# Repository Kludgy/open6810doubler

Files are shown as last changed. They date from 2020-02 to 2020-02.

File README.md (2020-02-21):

Open 6810 Doubler for the Atari 1050 Disk Drive
===============================================

This repository holds KiCad files for a PCB that, when used in conjunction with a custom Atari 1050 ROM, increases the available SRAM in a stock Atari 1050 Disk Drive from 128 bytes to 256 bytes. The 256 bytes of RAM is presumably enough to fit an entire sector's worth of data. Far more information can be found here: http://blog.3b2.sk/igi/post/Atari-1050-ICD-US-doubler.aspx

BOM: 
* 2x MCM6810.
* 2x Pin Header Strips to socket the PCB into the original 6810 location on the mainboard.
* 1x 24-pin socket on the mainboard as you wish.

Be advised the PCB will need to be socketed high enough to clear other components on the board.

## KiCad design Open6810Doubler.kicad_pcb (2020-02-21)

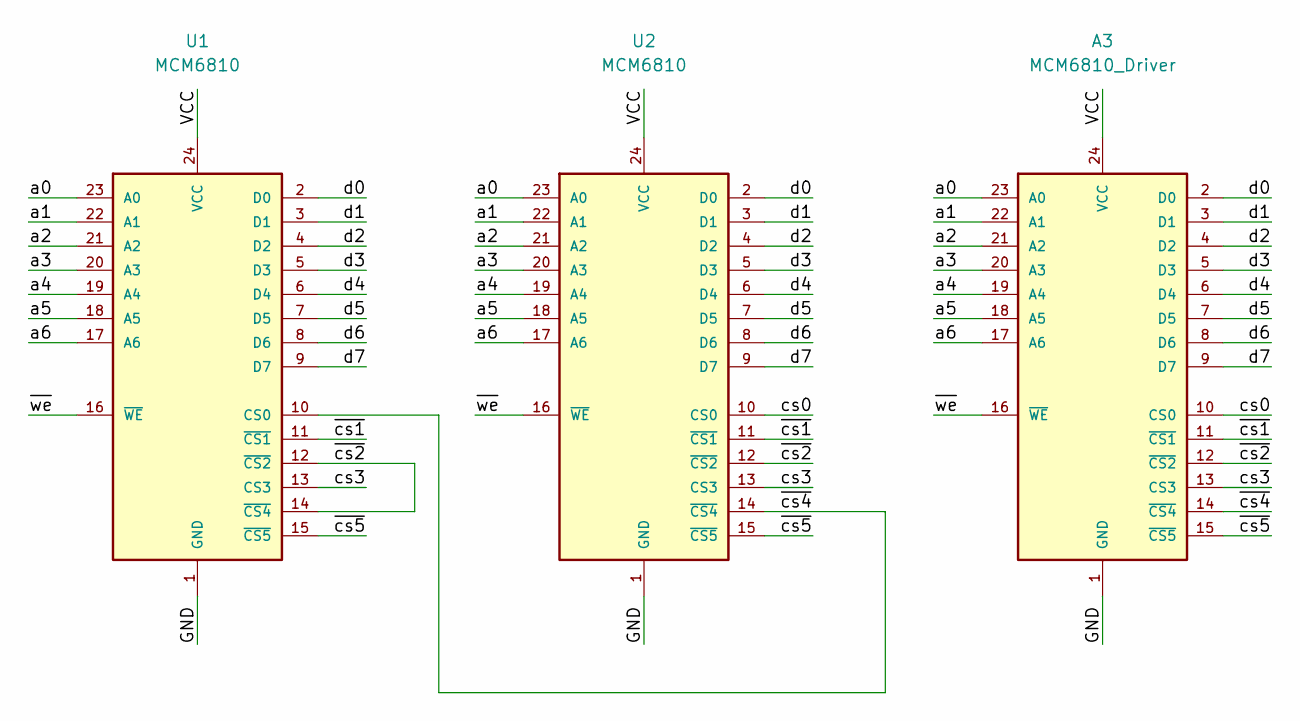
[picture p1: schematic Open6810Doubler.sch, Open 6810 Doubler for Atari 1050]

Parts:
A3: MCM6810_Driver; DIP-24_W15.24mm_LongPads
U1, U2: MCM6810; DIP-24_W15.24mm_LongPads

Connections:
/GND: A3.1 (GND), U1.1 (GND), U2.1 (GND)
/VCC: A3.24 (VCC), U1.24 (VCC), U2.24 (VCC)
/a0: A3.23 (A0), U1.23 (A0), U2.23 (A0)
/a1: A3.22 (A1), U1.22 (A1), U2.22 (A1)
/a2: A3.21 (A2), U1.21 (A2), U2.21 (A2)
/a3: A3.20 (A3), U1.20 (A3), U2.20 (A3)
/a4: A3.19 (A4), U1.19 (A4), U2.19 (A4)
/a5: A3.18 (A5), U1.18 (A5), U2.18 (A5)
/a6: A3.17 (A6), U1.17 (A6), U2.17 (A6)
/cs0: A3.10 (CS0), U2.10 (CS0)
/cs3: A3.13 (CS3), U1.13 (CS3), U2.13 (CS3)
/d0: A3.2 (D0), U1.2 (D0), U2.2 (D0)
/d1: A3.3 (D1), U1.3 (D1), U2.3 (D1)
/d2: A3.4 (D2), U1.4 (D2), U2.4 (D2)
/d3: A3.5 (D3), U1.5 (D3), U2.5 (D3)
/d4: A3.6 (D4), U1.6 (D4), U2.6 (D4)
/d5: A3.7 (D5), U1.7 (D5), U2.7 (D5)
/d6: A3.8 (D6), U1.8 (D6), U2.8 (D6)
/d7: A3.9 (D7), U1.9 (D7), U2.9 (D7)
/~cs1: A3.11 (~CS1), U1.11 (~CS1), U2.11 (~CS1)
/~cs2: A3.12 (~CS2), U1.12 (~CS2), U1.14 (~CS4), U2.12 (~CS2)
/~cs4: A3.14 (~CS4), U1.10 (CS0), U2.14 (~CS4)
/~cs5: A3.15 (~CS5), U1.15 (~CS5), U2.15 (~CS5)
/~we: A3.16 (~WE~), U1.16 (~WE~), U2.16 (~WE~)

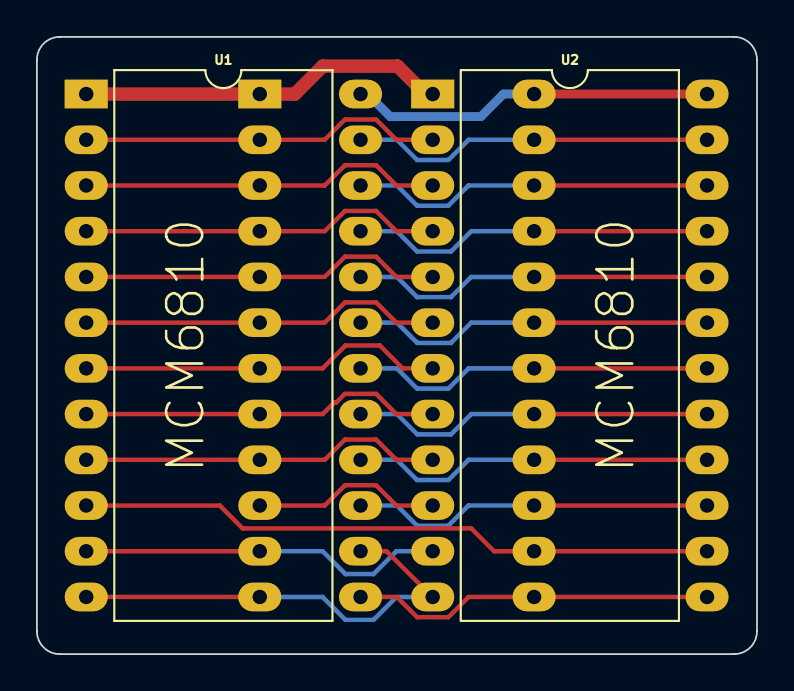
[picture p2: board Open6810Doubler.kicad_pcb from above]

Board: 2 copper layers, 40.0 x 34.3 mm, 3 parts (0 on the bottom side), 24 nets.
